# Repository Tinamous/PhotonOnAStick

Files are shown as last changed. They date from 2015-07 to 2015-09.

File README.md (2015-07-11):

# PhotonOnAStick
Particle Photon Prototyping board on a USB Stick

## Currently untested (11 July 2015). PCBs ordered for testing.

## Use Case

* Prototype post breadboard. 
* Connection of sensors, LEDs, SparkFun style breakout boards etc.
* Deployed Thing on a Stick where the Photon may be used to make an internet connected sensor for a room, or lighting or ??? and can be plugged into a USB wall adaptor.
* Using readily available wall plugs board may be connected:
** with the board vertical, Photon facing outwards flat to the wall.
** with the board horizontal, Photon facing upwards. 
* These options makes for a nice option for uplighting (internet controlled nightlight?), or a room sensor.
* Other power adaptors exist, e.g. USB in a multi-gang outlet.

## Usage

* USB powered by plugging into a USB A socket on a USB Wall Adaptor, or A -> Micro B on the Particle Photon. Do not connect both at once.
* Top layer is mainly for 0805 devices (and through hole).
* Bottom layer is for 1206 devices (and through hole).

## Botton (looking at the baord with USB connector to the left)
* A0-A7 Analog signals come out to the option of a round test point (solder connection) via an 0805. Can be resistor, 0 ohm link or ....
* A0-A7 Analog signals also come out to a 1206 package with the other side unconnected so this can have a wire tacked on as needed.
** This arrangement may be used to provide either imput impedance/capacitance filter to the analog signal, 
** or by connecting the unterminated end to GND or 3V3 this can provice half of a potential divider for a sensor - the sensor may be providing the other half.
* +5V, Gnd, Tx and Rx come out to a 1206 only. Allows for a resitor and/or wire tacking.

## Center
* Top layer in the middle is a SO16 package outline, can be used for SO8 or anything that would fit. Pins 1-8 go to connectors by the USB port, 9-16 by the bottom of the Photon.
* Top 2 connectors in the middle of the Photon have +5V, +3V3 and Gnd available.

## Top (looking at the baord with USB connector to the left)
* 3v3, VBat and Gnd brought out to 4 pin connector. Pin 2 unconnected (may be used for polarity).
* D0-D7 connected to 1206 package on bottom layer with other end unconnected available for wire.
* D0-D7 on top layer go to 0805 package which is liked to a second 0805 with the far end connected to ground.
** This arrangement allows D0-D7 to be connected to a (0805) LED then a (0805)current limiting resitor on the top layer
** or to provide a pull down where the input is connected to the middle of the pins 0805 packages.

## Prototyping area (Right hand side looking at the baord with USB connector to the left).
* Top rail is 3v3 from the Photon (3)
* Second rail down is GND (G)
* Bottom rail is +5V (5)
* 3V3 and GND have a 0805 connection for a capacitor.
* Each pair of rows have possible connection for 0805 and 1206 device near the Photon to allow for capacitor, resistor or LED.
* Only power rails are connected hole to hole.
* 8 1206 or 8 * 2 0805s are available on the right, again for LEDs, Sensors, Resistors or Capacitors. 
** The 2x 0805 combination allows for a LED + resistor. Either side of the 1206 or 0805 pair are connected to the pins to the outside of them.

## Spark Photon
* This board is designed for the Particle Photon. It does need headers though.
* The Particle Core (Spark Core) may also be used.

## Eagle Libraries Used:

Particle Photon Library: https://github.com/spark/photon/tree/master/libraries
SparkFun: https://github.com/sparkfun/SparkFun-Eagle-Libraries

## Versioning

* Board will have multiple major versions. e.g.
** V1 A0-A8 1206/0805's unterminated.
** V1.x bug fixes for V1 board.

** V2 A0-A8 1206/0805's terminated with +5 or GND based on layer
** V2.x bug fixes for V2 board.

## Ideas

### Different versions

* Change A0-A8 1206 packages so unconnected end is connected to 
* Much narrower (just room for Photon)
* Wonly - USB port at Top Right corner to allow for top exit wall adaptors where USB socket is perpendicular to the wall.
* Surface mount photon

* Timer version. LED/LCD/OLED dispay. Sensor to allow for setting and starting of timer (Hands free)

## Bugs

* Missing Open Hardware Logo.

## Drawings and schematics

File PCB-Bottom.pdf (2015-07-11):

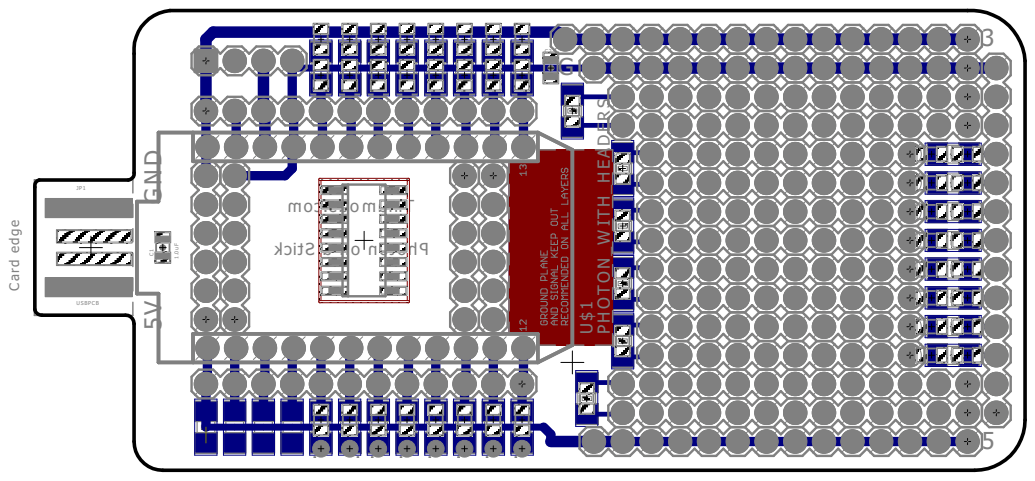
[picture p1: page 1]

moc. s uo ma ni T kci t S a no not ohP GND 5V 3 G 5 JP1 U$1 C1 C2 USBPCB PHOTON_W ITH_HEADERS 1.0uF Card edge

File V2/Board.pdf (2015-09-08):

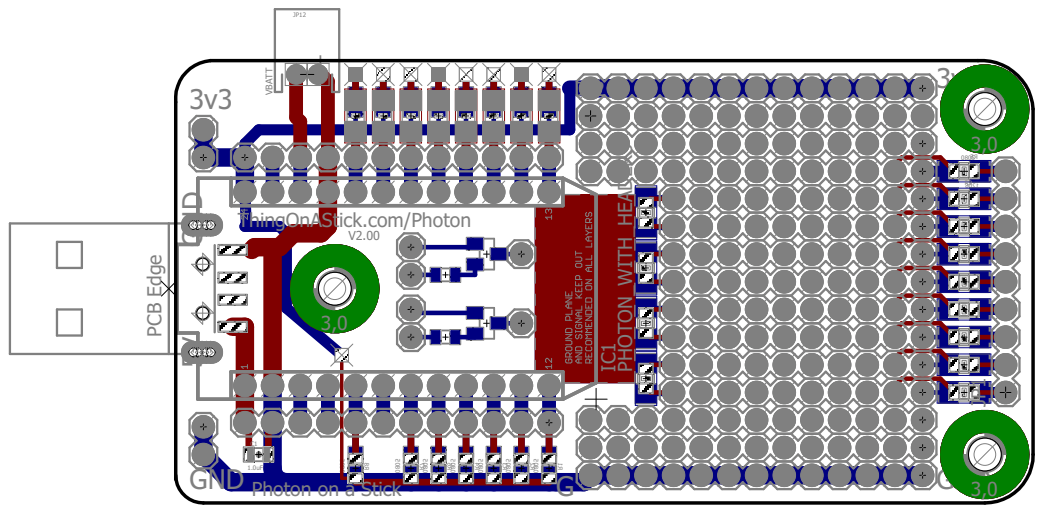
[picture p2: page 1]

0805 0805 0805 0805 0805 0805 0805 6021 R1R2R3R4R6R7R8 5R GND 5V G PCB Edge - + ThingOnAStick.com/Photon Photon on a Stick 3v3 GND V2.00 VBAT 3v3 GND IC1 C1 JP2 JP1 R9 JP12 PHOTON_WITH_HEADERS 1.0uF 0805 3,0 3,0 3,0

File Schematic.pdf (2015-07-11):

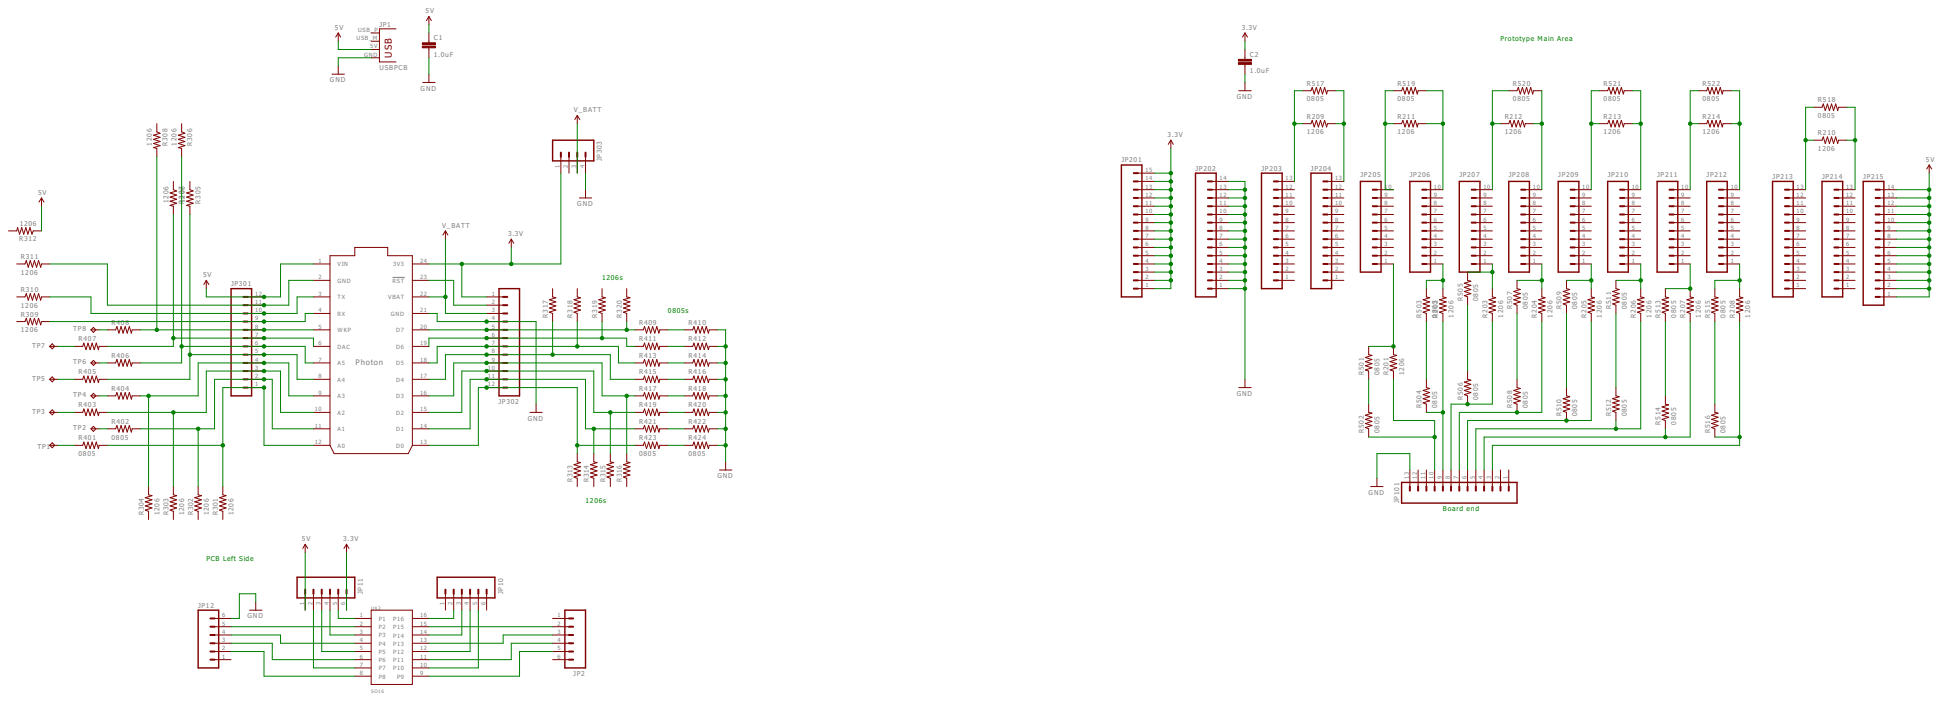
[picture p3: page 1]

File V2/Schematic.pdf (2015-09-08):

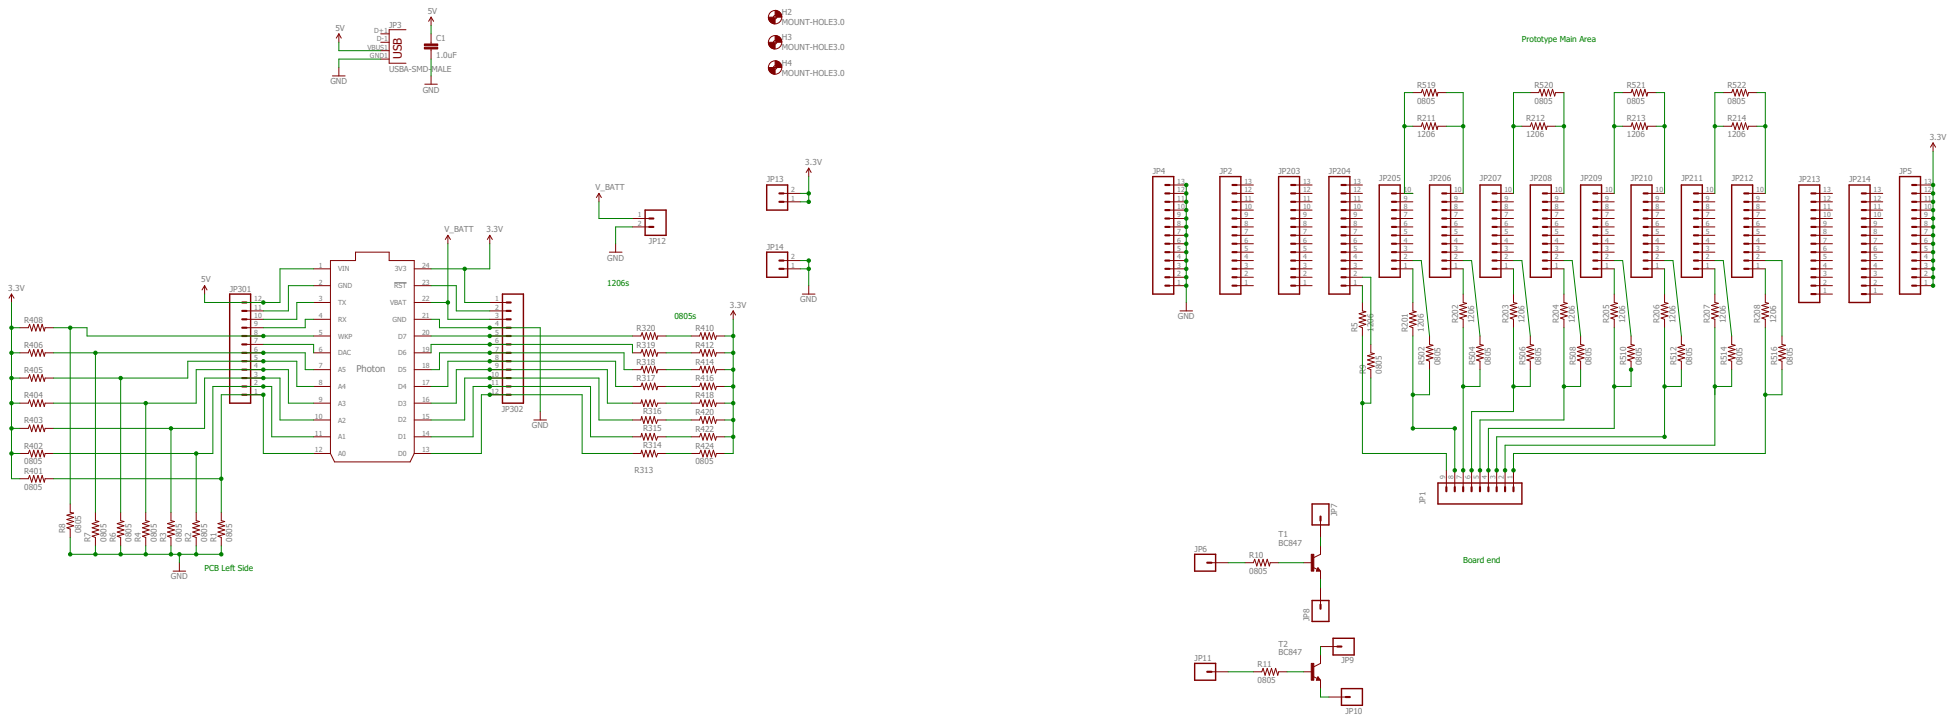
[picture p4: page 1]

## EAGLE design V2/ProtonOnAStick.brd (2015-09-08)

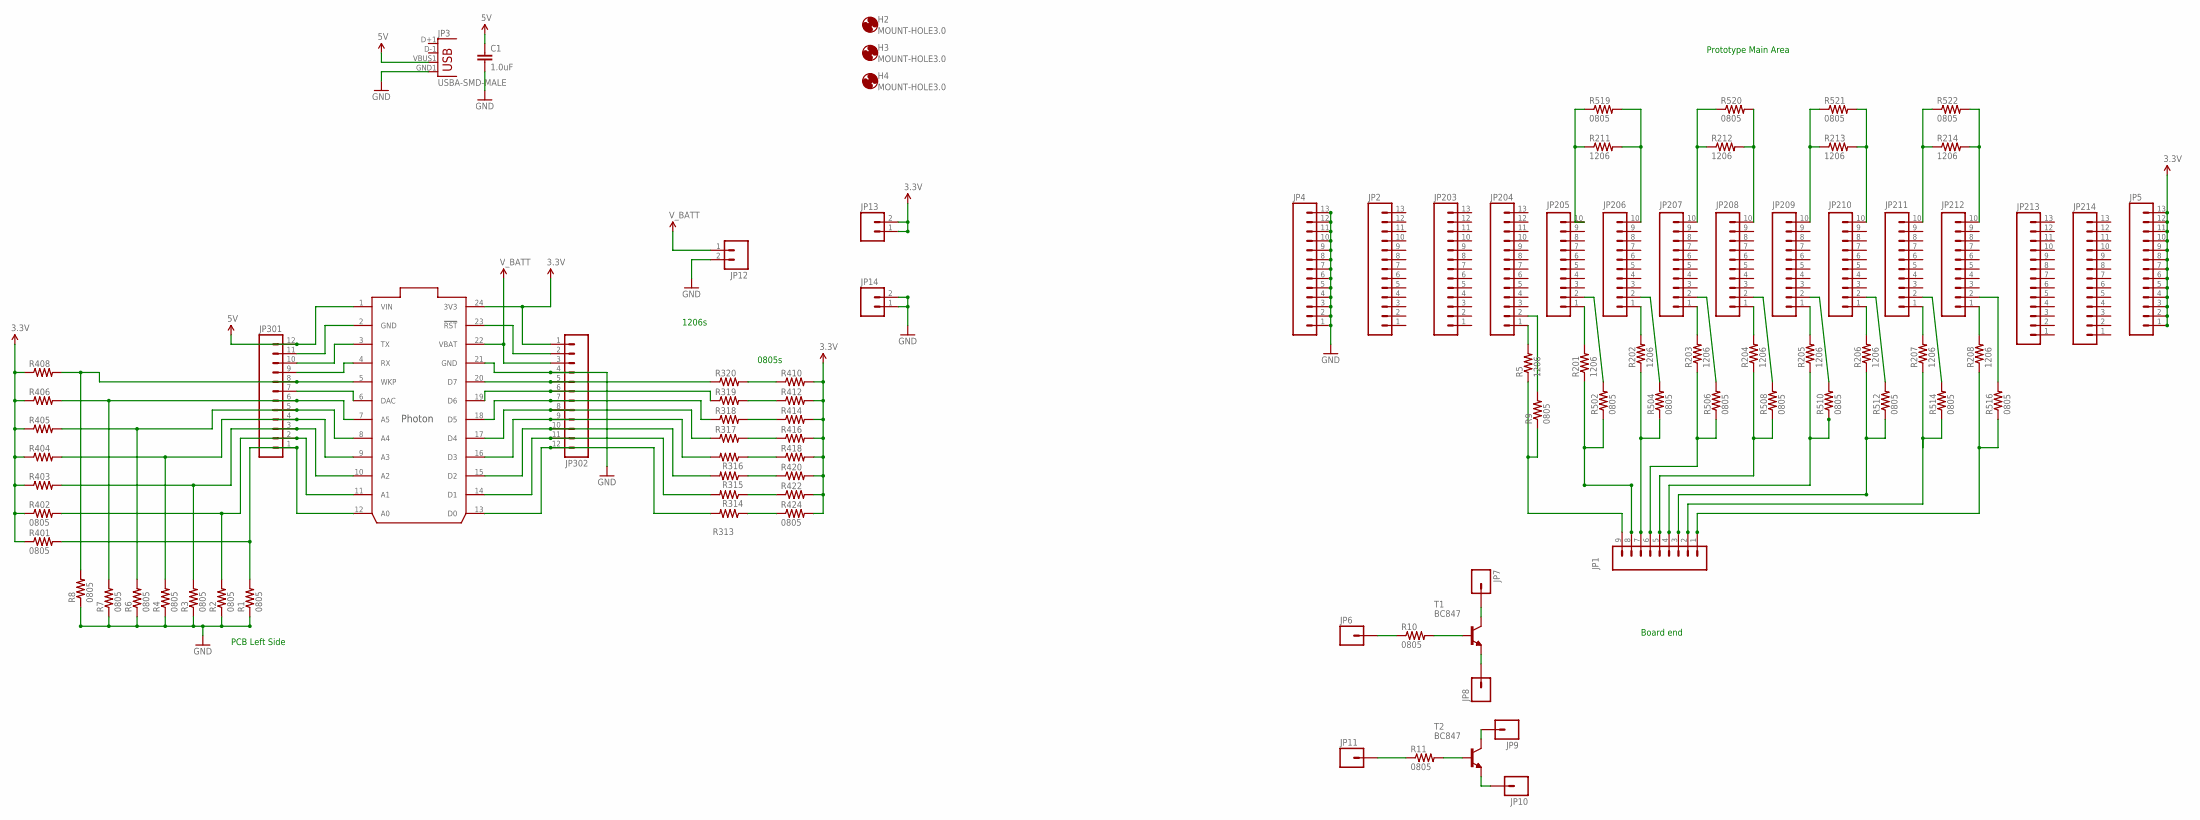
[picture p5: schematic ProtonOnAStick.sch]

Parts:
C1: 1.0uF; 0805-CAP
H2, H3, H4: MOUNT-HOLE3.0; 3,0
IC1: PHOTON_WITH_HEADERS; PHOTON
JP1: M09; 1X09
JP2, JP4, JP5, JP203, JP204, JP213, JP214: M13; 1X13
JP3: USBA-SMD-MALE; USB-A-SMT-MALE
JP6, JP7, JP8, JP9, JP10, JP11: M01PTH; 1X01
JP12: M02JST-PTH-2; JST-2-PTH
JP13, JP14: M02PTH; 1X02
JP205, JP206, JP207, JP208, JP209, JP210, JP211, JP212: M10SILK_FEMALE_PTH; 1X10
JP301, JP302: M12PTH; 1X12
R1, R2, R3, R4, R6, R7, R8, R9, R10, R11, R401, R402, R403, R404, R405, R406, R408, R410, R412, R414, R416, R418, R420, R422, R424, R502, R504, R506, R508, R510, R512, R514, R516, R519, R520, R521, R522: 0805
R5, R201, R202, R203, R204, R205, R206, R207, R208, R211, R212, R213, R214, R313, R314, R315, R316, R317, R318, R319, R320: 1206
T1, T2: BC847; SOT23

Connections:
3.3V: IC1.24 (3V3), JP5.1, JP5.2, JP5.3, JP5.4, JP5.5, JP5.6, JP5.7, JP5.8, JP5.9, JP5.10, JP5.11, JP5.12, JP5.13, JP13.1, JP13.2, JP302.1, R401.1, R402.1, R403.1, R404.1, R405.1, R406.1, R408.1, R410.2, R412.2, R414.2, R416.2, R418.2, R420.2, R422.2, R424.2
5V: C1.1, IC1.1 (VIN), JP3.VBUS1 (VBUS), JP301.12
GND: C1.2, IC1.2 (GND), IC1.21 (GND), JP3.GND1 (GND), JP4.1, JP4.2, JP4.3, JP4.4, JP4.5, JP4.6, JP4.7, JP4.8, JP4.9, JP4.10, JP4.11, JP4.12, JP4.13, JP12.2, JP14.1, JP14.2, JP301.11, JP302.4, R1.1, R2.1, R3.1, R4.1, R6.1, R7.1, R8.1
unnamed: JP6.1, R10.1
unnamed: JP206.1, R202.2
unnamed: JP204.1, R5.2
unnamed: IC1.3 (TX), JP301.10
unnamed: IC1.4 (RX), JP301.9
unnamed: IC1.5 (WKP), JP301.8, R8.2, R408.2
unnamed: IC1.6 (DAC), JP301.7
unnamed: IC1.7 (A5), JP301.6, R7.2, R406.2
unnamed: IC1.8 (A4), JP301.5, R6.2, R405.2
unnamed: IC1.9 (A3), JP301.4, R4.2, R404.2
unnamed: IC1.10 (A2), JP301.3, R3.2, R403.2
unnamed: IC1.11 (A1), JP301.2, R2.2, R402.2
unnamed: IC1.12 (A0), JP301.1, R1.2, R401.2
unnamed: JP1.9, R5.1, R9.1
unnamed: R10.2, T1.1 (B)
unnamed: IC1.18 (D5), JP302.7, R318.1
unnamed: IC1.17 (D4), JP302.8, R317.1
unnamed: IC1.16 (D3), JP302.9, R316.2
unnamed: IC1.15 (D2), JP302.10, R315.2
unnamed: IC1.14 (D1), JP302.11, R314.2
unnamed: IC1.13 (D0), JP302.12, R313.2
unnamed: JP209.1, R205.2
unnamed: JP211.2, R514.2
unnamed: IC1.23 (!RST), JP302.2
unnamed: R320.2, R410.1
unnamed: JP207.1, R203.2
unnamed: JP208.1, R204.2
unnamed: JP1.7, R202.1, R504.1
unnamed: JP1.6, R203.1, R506.1
unnamed: JP1.5, R204.1, R508.1
unnamed: JP1.4, R205.1, R510.1
unnamed: JP205.1, R201.2
unnamed: JP1.8, R201.1, R502.1
unnamed: JP210.1, R206.2
unnamed: JP211.1, R207.2
unnamed: JP1.3, R206.1, R512.1
unnamed: JP1.2, R207.1, R514.1
unnamed: IC1.20 (D7), JP302.5, R320.1
unnamed: IC1.19 (D6), JP302.6, R319.1
unnamed: JP212.2, R516.2
unnamed: JP7.1, T1.3 (C)
unnamed: JP210.2, R512.2
unnamed: R313.1, R424.1
unnamed: R314.1, R422.1
unnamed: R315.1, R420.1
unnamed: R316.1, R418.1
unnamed: R317.2, R416.1
unnamed: R318.2, R414.1
unnamed: R319.2, R412.1
unnamed: JP209.2, R510.2
unnamed: JP206.2, R504.2
unnamed: JP205.2, R502.2
unnamed: JP207.2, R506.2
unnamed: JP8.1, T1.2 (E)
unnamed: JP212.1, R208.2
unnamed: JP1.1, R208.1, R516.1
unnamed: JP204.2, R9.2
unnamed: JP11.1, R11.1
unnamed: R11.2, T2.1 (B)
unnamed: JP9.1, T2.3 (C)
unnamed: JP10.1, T2.2 (E)
unnamed: JP205.10, R211.1, R519.1
unnamed: JP206.10, R211.2, R519.2
unnamed: JP208.10, R212.2, R520.2
unnamed: JP210.10, R213.2, R521.2
unnamed: JP212.10, R214.2, R522.2
unnamed: JP207.10, R212.1, R520.1
unnamed: JP209.10, R213.1, R521.1
unnamed: JP211.10, R214.1, R522.1
unnamed: JP208.2, R508.2
V_BATT: IC1.22 (VBAT), JP12.1, JP302.3

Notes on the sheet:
PCB Left Side
Prototype Main Area
0805s
1206s
Board end

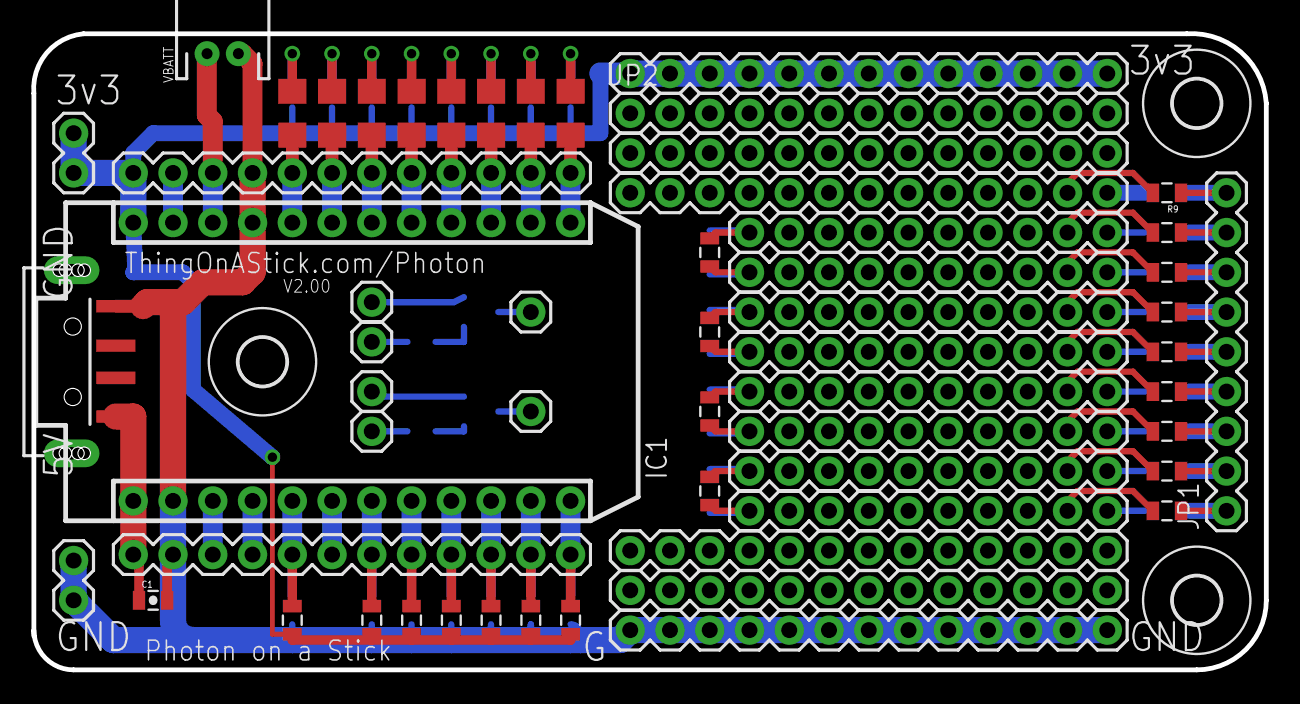
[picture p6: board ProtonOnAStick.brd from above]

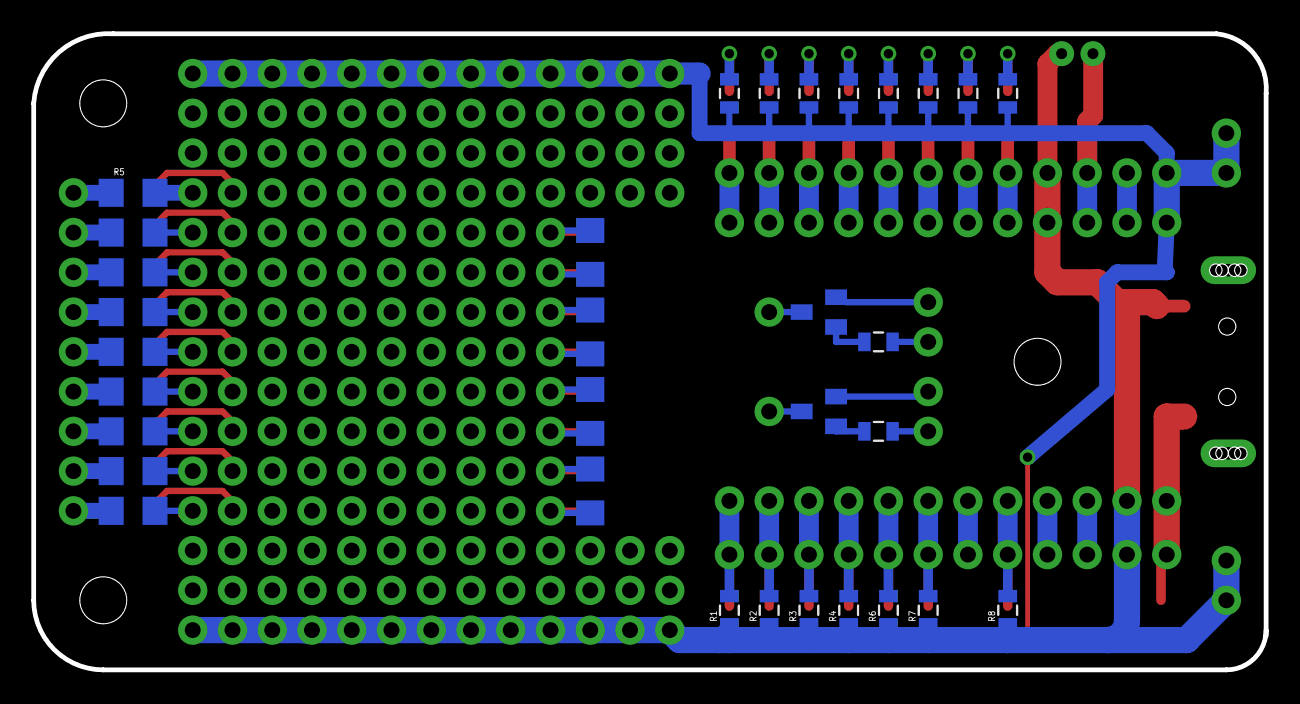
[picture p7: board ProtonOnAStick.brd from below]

Board: 2 copper layers, 78.8 x 40.6 mm, 93 parts (32 on the bottom side), 74 nets.

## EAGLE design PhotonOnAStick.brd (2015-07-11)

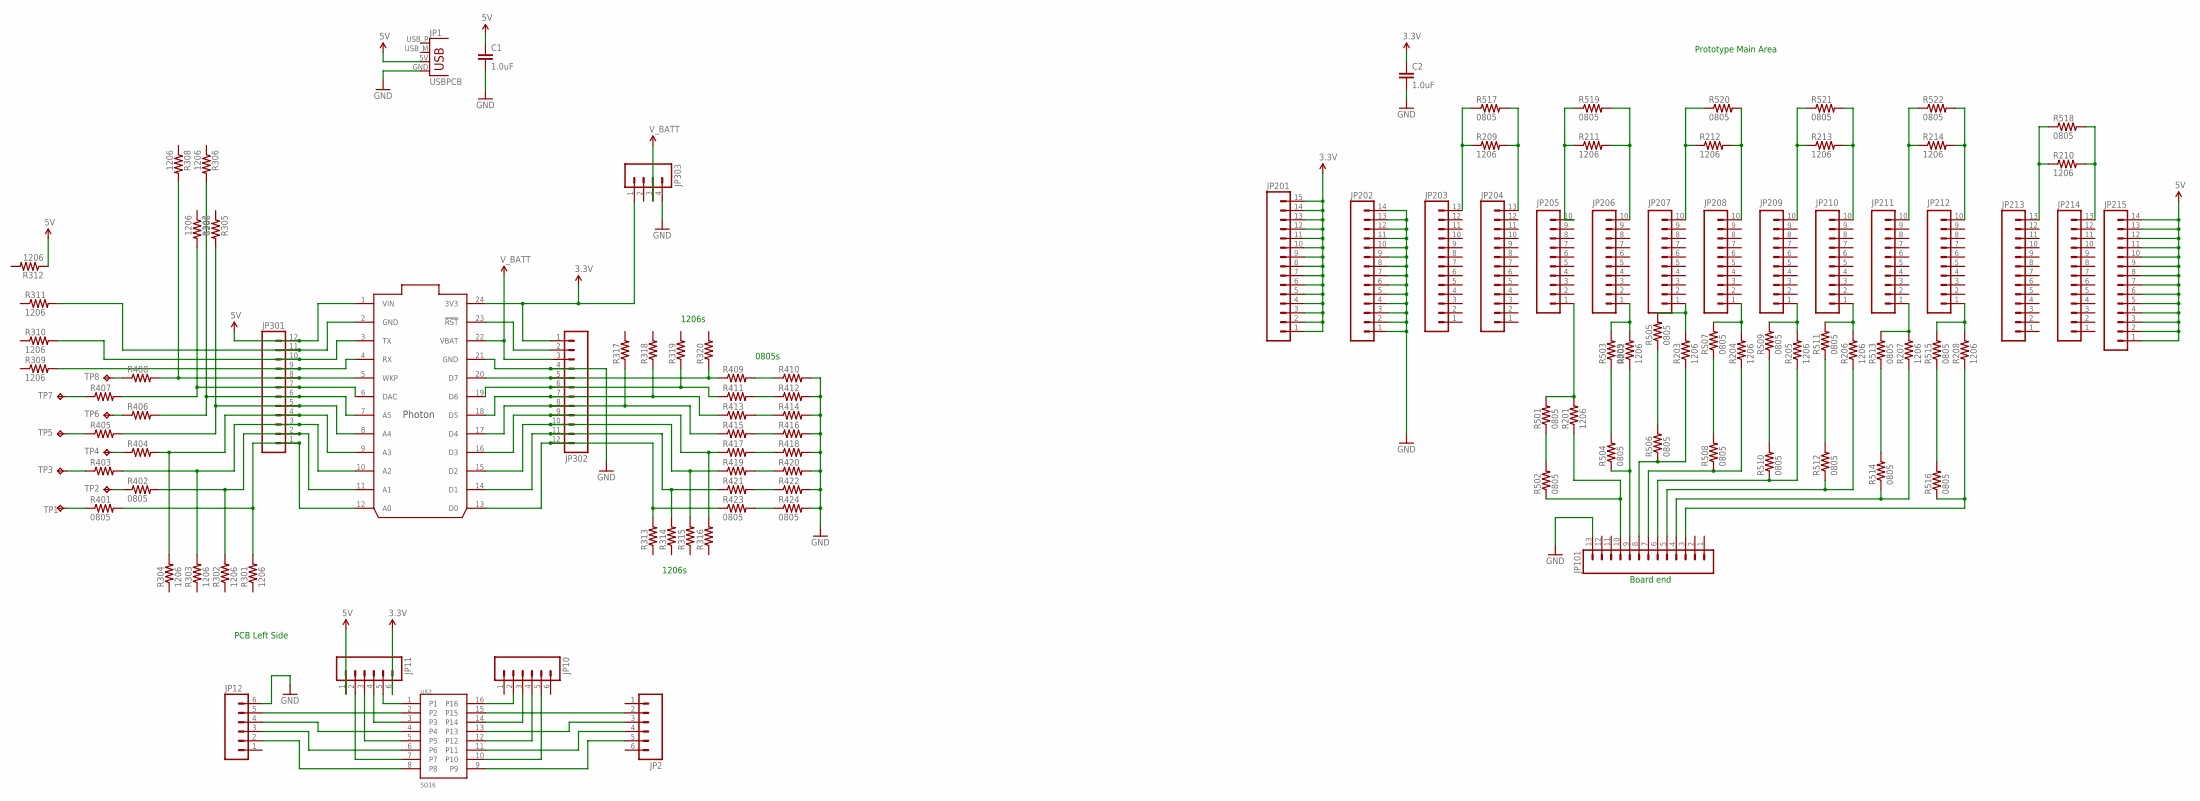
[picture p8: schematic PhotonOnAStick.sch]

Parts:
C1, C2: 1.0uF; 0805-CAP
JP1: USBPCB; USB-A-PCB
JP2, JP10, JP11, JP12: M06SILK_FEMALE_PTH; 1X06
JP101, JP203, JP204, JP213, JP214: M13; 1X13
JP201: M15; 1X15
JP202, JP215: M14; 1X14
JP205, JP206, JP207, JP208, JP209, JP210, JP211, JP212: M10SILK_FEMALE_PTH; 1X10
JP301, JP302: M12PTH; 1X12
JP303: M04PTH; 1X04
R201, R202, R203, R204, R205, R206, R207, R208, R209, R210, R211, R212, R213, R214, R301, R302, R303, R304, R305, R306, R307, R308, R309, R310, R311, R312, R313, R314, R315, R316, R317, R318, R319, R320: 1206
R401, R402, R403, R404, R405, R406, R407, R408, R409, R410, R411, R412, R413, R414, R415, R416, R417, R418, R419, R420, R421, R422, R423, R424, R501, R502, R503, R504, R505, R506, R507, R508, R509, R510, R511, R512, R513, R514, R515, R516, R517, R518, R519, R520, R521, R522: 0805
TP1, TP2, TP3, TP4, TP5, TP6, TP7, TP8: TPB1,27; B1,27
U$1: PHOTON_WITH_HEADERS; PHOTON
U$2: SO16

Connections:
3.3V: C2.1, JP11.6, JP201.1, JP201.2, JP201.3, JP201.4, JP201.5, JP201.6, JP201.7, JP201.8, JP201.9, JP201.10, JP201.11, JP201.12, JP201.13, JP201.14, JP201.15, JP302.1, JP303.1, U$1.24 (3V3)
5V: C1.1, JP1.5V (VBUS), JP11.1, JP215.1, JP215.2, JP215.3, JP215.4, JP215.5, JP215.6, JP215.7, JP215.8, JP215.9, JP215.10, JP215.11, JP215.12, JP215.13, JP215.14, JP301.12, R312.1, U$1.1 (VIN)
GND: C1.2, C2.2, JP1.GND, JP12.6, JP101.13, JP202.1, JP202.2, JP202.3, JP202.4, JP202.5, JP202.6, JP202.7, JP202.8, JP202.9, JP202.10, JP202.11, JP202.12, JP202.13, JP202.14, JP302.4, JP303.4, R410.2, R412.2, R414.2, R416.2, R418.2, R420.2, R422.2, R424.2, U$1.21 (GND)
unnamed: JP214.13, R210.2, R518.2
unnamed: JP206.1, R202.2, R503.2
unnamed: JP301.11, R311.2, U$1.2 (GND)
unnamed: JP301.10, R310.2, U$1.3 (TX)
unnamed: JP301.9, R309.2, U$1.4 (RX)
unnamed: JP301.8, R308.2, R408.2, U$1.5 (WKP)
unnamed: JP301.7, R307.2, R407.2, U$1.6 (DAC)
unnamed: JP301.6, R306.2, R406.2, U$1.7 (A5)
unnamed: JP301.5, R305.2, R405.2, U$1.8 (A4)
unnamed: JP301.4, R304.2, R404.2, U$1.9 (A3)
unnamed: JP301.3, R303.2, R403.2, U$1.10 (A2)
unnamed: JP301.2, R302.2, R402.2, U$1.11 (A1)
unnamed: JP301.1, R301.2, R401.2, U$1.12 (A0)
unnamed: JP204.13, R209.2, R517.2
unnamed: JP213.13, R210.1, R518.1
unnamed: JP302.7, R318.1, R413.1, U$1.18 (D5)
unnamed: JP302.8, R317.1, R415.1, U$1.17 (D4)
unnamed: JP302.9, R316.2, R417.1, U$1.16 (D3)
unnamed: JP302.10, R315.2, R419.1, U$1.15 (D2)
unnamed: JP302.11, R314.2, R421.1, U$1.14 (D1)
unnamed: JP302.12, R313.2, R423.1, U$1.13 (D0)
unnamed: JP209.1, R205.2, R509.2
unnamed: R513.1, R514.2
unnamed: JP302.2, U$1.23 (!RST)
unnamed: R409.2, R410.1
unnamed: JP207.1, R203.2, R505.2
unnamed: JP208.1, R204.2, R507.2
unnamed: JP101.9, R202.1, R504.1
unnamed: JP101.8, R203.1, R506.1
unnamed: JP101.7, R204.1, R508.1
unnamed: JP101.6, R205.1, R510.1
unnamed: JP205.1, R201.2, R501.2
unnamed: JP101.10, R201.1, R502.1
unnamed: JP210.1, R206.2, R511.2
unnamed: JP211.1, R207.2, R513.2
unnamed: JP101.5, R206.1, R512.1
unnamed: JP101.4, R207.1, R514.1
unnamed: JP302.5, R320.1, R409.1, U$1.20 (D7)
unnamed: JP302.6, R319.1, R411.1, U$1.19 (D6)
unnamed: R515.1, R516.2
unnamed: R511.1, R512.2
unnamed: R423.2, R424.1
unnamed: R421.2, R422.1
unnamed: R419.2, R420.1
unnamed: R417.2, R418.1
unnamed: R415.2, R416.1
unnamed: R413.2, R414.1
unnamed: R411.2, R412.1
unnamed: R509.1, R510.2
unnamed: R503.1, R504.2
unnamed: R501.1, R502.2
unnamed: R505.1, R506.2
unnamed: JP203.13, R209.1, R517.1
unnamed: JP212.1, R208.2, R515.2
unnamed: JP101.3, R208.1, R516.1
unnamed: R408.1, TP8.TP
unnamed: R407.1, TP7.TP
unnamed: R405.1, TP5.TP
unnamed: R404.1, TP4.TP
unnamed: R403.1, TP3.TP
unnamed: R401.1, TP1.TP
unnamed: R402.1, TP2.TP
unnamed: R406.1, TP6.TP
unnamed: JP205.10, R211.1, R519.1
unnamed: JP206.10, R211.2, R519.2
unnamed: JP208.10, R212.2, R520.2
unnamed: JP210.10, R213.2, R521.2
unnamed: JP212.10, R214.2, R522.2
unnamed: JP207.10, R212.1, R520.1
unnamed: JP209.10, R213.1, R521.1
unnamed: JP211.10, R214.1, R522.1
unnamed: JP11.5, U$2.1
unnamed: JP11.4, U$2.3
unnamed: JP11.3, U$2.5
unnamed: JP11.2, U$2.7
unnamed: JP12.5, U$2.2
unnamed: JP12.4, U$2.4
unnamed: JP12.3, U$2.6
unnamed: JP12.2, U$2.8
unnamed: JP10.2, U$2.16
unnamed: JP2.2, U$2.15
unnamed: JP10.3, U$2.14
unnamed: JP10.4, U$2.12
unnamed: JP10.5, U$2.10
unnamed: JP2.3, U$2.13
unnamed: JP2.4, U$2.11
unnamed: JP2.5, U$2.9
unnamed: R507.1, R508.2
V_BATT: JP302.3, JP303.3, U$1.22 (VBAT)

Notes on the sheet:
PCB Left Side
Prototype Main Area
0805s
1206s
Board end

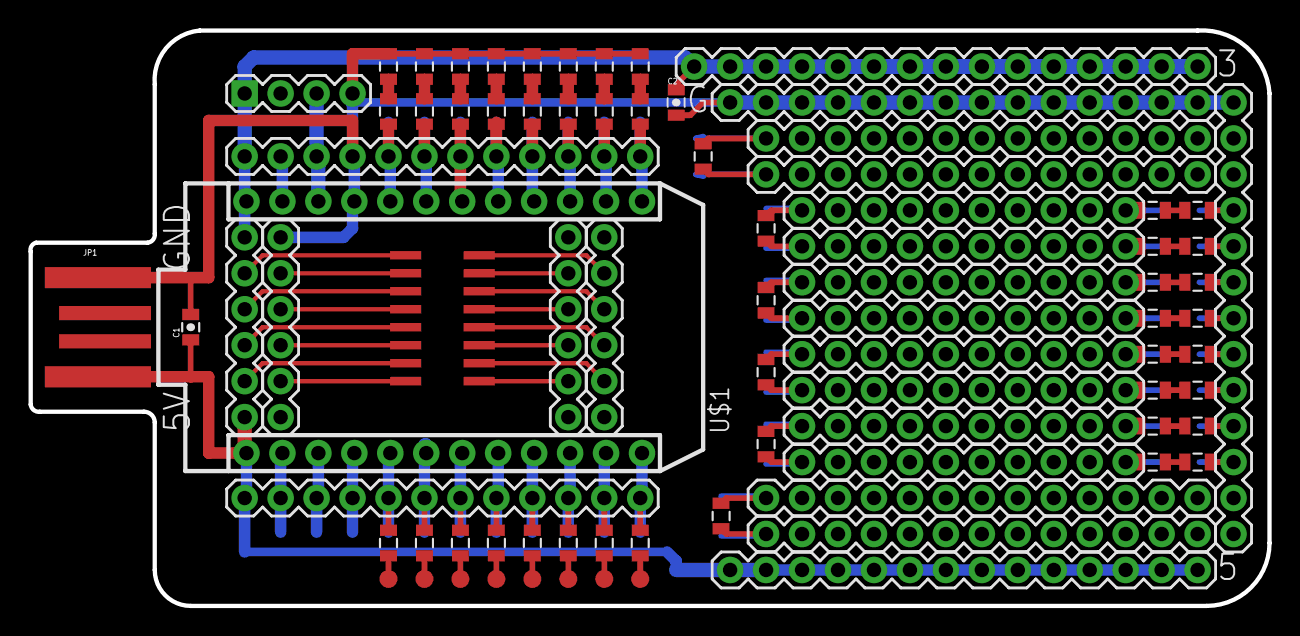
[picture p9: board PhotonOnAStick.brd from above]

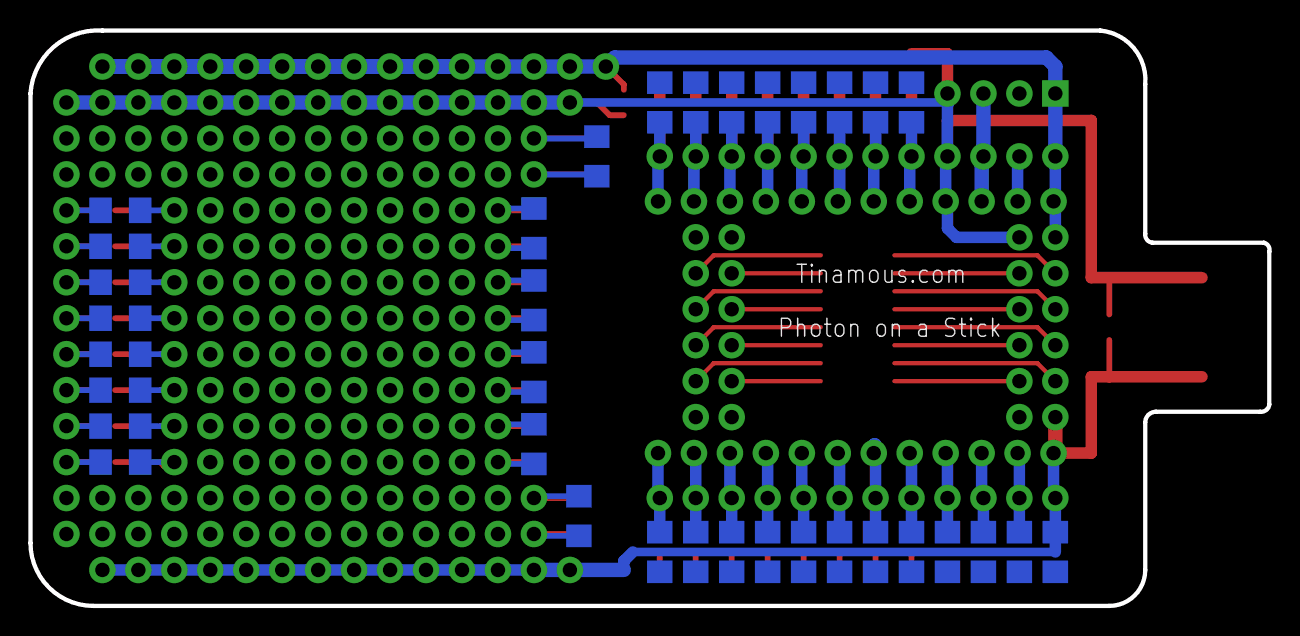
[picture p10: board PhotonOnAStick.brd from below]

Board: 2 copper layers, 87.5 x 40.6 mm, 116 parts (34 on the bottom side), 92 nets.

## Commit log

2015-07-11 Initial version.
    [ProtonOnAStick.brd, ProtonOnAStick.sch]
2015-07-11 Fixed filename naming
    [PhotonOnAStick.brd, PhotonOnAStick.sch]
2015-07-11 Added pdf's of schematic and PCB top/bottom
2015-09-08 Added V2 boards.
    [ProtonOnAStick.brd, ProtonOnAStick.sch]

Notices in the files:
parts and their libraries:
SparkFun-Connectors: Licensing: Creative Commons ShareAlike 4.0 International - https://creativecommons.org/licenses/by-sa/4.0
